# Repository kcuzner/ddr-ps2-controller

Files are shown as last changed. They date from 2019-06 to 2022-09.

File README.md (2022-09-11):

# Dance-Dance-Revolution PS2 Controller

Kevin Cuzner

## Introduction

This is my attempt at a low-cost, but high quality DIY DDR controller which is compatible with the Sony PlayStation 2.

The firmware is based loosely on my [Pop-N-Music PS2 Controller](https://github.com/kcuzner/pop-n-music-controller).
though I've rewritten it to be closer to my current style.

Although it would be cool to use an STM32 or other advanced ARM controller, that is overkill for what this is. Turns
out, a $0.60 AVR microcontroller can meet all the digital requirements without even needing a 3.3V regulator. To that
end, here is the main featureset:

 - ATTiny20 microcontroller (QFN package, 12 I/O). There are two personalities:
   - The PSX bus interface. This takes input from up to 6 buttons and operates the upstream PSX bus to the PlayStation
     2.
   - The switch controller. This takes input from up to 4 foot switches and produces a single output which is cabled to
     the PSX bux interface board.
 - Single PCB which fits both personalities.
 - Edge-facing LEDs for pad illumination.
   - Strangely enough, it was cheaper to just use a constant-current controlled LED driver than to use a discrete MOSFET
     of an appropriate size.

## Project Status

 - This project has not been fully assembled or tested. But:
 - Firmware builds and installs on both board personalities.
 - The LED/Switch boards work great! Mostly. Some quirks with the LEDs always being partially on,
   but whatever.
 - With a [USB-PS2 adapter](https://www.amazon.com/gp/product/B01J4JVFXI) I've verified on an
   oscilloscope that the controller board can be polled and that it appears to send back the
   correct responses. So the PSX bus implementation is at least superficially correct.
 - The switch boards can connect to the controller board and on an oscilloscope I've verified that
   everything toggles.

Some things still remain I can think of off the top of my head:

 - I need to test it with an actual PS2. Now to convince my wife to let me touch her PS2...
 - I need to verify that the button/switch mappings are correct for a dance pad. I unfortunately
   didn't mark the PCB silkscreen in any way for that, so I'm going to have to resort to colored
   tape, paint, or something else to keep the myriad cables straight while wiring this up.
 - I need to actually construct the wood/metal/plastic enclosure for this. I have a plan, but it's
   not posted here.

## References

 - http://www.raphnet.net/electronique/psx_adaptor/Playstation.txt
 - https://gist.github.com/scanlime/5042071
 - https://store.curiousinventor.com/guides/PS2/
 - https://blog.nearfuturelaboratory.com/2008/06/19/playstation2-logic-analysis/

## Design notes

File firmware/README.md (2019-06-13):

# DDR PS2 Controller Firmware

This firmware is for the ATTiny20 and uses avr-gcc. It creates two personalities which are separate and distinct
functions of the single PCB:

 - The Controller: This is the PSX Bus controller which handles input from 6 switches and communicates over the PSX bus.
 - The Switch: Each foot switch has 4 separate physical switches. This collates the 4 switches into a single control
   line and also operates some LEDs.

## Build Prerequisites

 - make
 - avr-gcc
 - avr-binutils
 - avrdude

## How to build

This uses a recursive makefile system to build the two personality components. To begin the build process, the `make`
command is invoked from this directory. It will pass along the target to the component makefiles. Here are some example
invocations:

```
$ make
```

This invocation will build the default target for both components.

```
$ make all switch
```

This invocation will build the `all` target for the switch component.

```
$ make clean
```

This invocation will build the `clean` target for both components.

```
$ make install controller
```

This invocation will build the `install` target for the controller component

To describe the format for the commands more generally, invoking `make` in this folder has the following syntax:

```
make [TARGET] [[COMPONENT] [[COMPONENT]..]]
```

Where each `[TARGET]` is something that can be built in the subdirectory and each `[COMPONENT]` is a subdirectory in
this folder which has been designated in the `Makefile` as a component subdirectory.

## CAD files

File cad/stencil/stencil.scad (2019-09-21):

// Solder Stencil, tuned for the MP Select Mini 3D Printer
// Material: ABS
// Nozzle: 0.2mm
// Layer height: <0.1mm

// We use various dimensions, depending on where I pulled them from (PCB CAD is inches, physical measurements are mm)
inches = 25.4;
mm = 1;
degrees = 1;

//Set up for higher resolution circles
$fn = 60;

//Variables
//Generally:
//  Width is the X direction
//  Length is the Y direction

pad_manifold = 0.01 * mm; //padding for maintaining a manifold (avoiding zero-width shapes)

/////// PCB Dimensions

pcb_width = 100 * mm;
pcb_length = 40 * mm;
pcb_thickness = 1.6 * mm;

/////// Solder Paste Properties

// The solder paste should be exported with the entire page as its area, but
// without board edges. The board's corner is at a nice even number.
paste_origin_x = 100 * mm;
paste_origin_y = 90 * mm;

/////// Stencil

stencil_width = pcb_width + 10 * mm;
stencil_length = pcb_length + 10 * mm;
stencil_thickness = 0.1 * mm;

/////////////// Solder Stencil //////////////////

module PasteLayer() {
  translate([-paste_origin_x - pcb_width/2, -paste_origin_y - pcb_length/2, 0])
    linear_extrude(height=pcb_thickness + stencil_thickness + pad_manifold)
      import("../ddr-ps2-controller-F_Paste.svg");
}

module PcbStandin() {
  translate([-pcb_width/2, -pcb_length/2, -pad_manifold])
    cube([pcb_width, pcb_length, pcb_thickness + pad_manifold]);
}

module SolderStencil() { //`make` me
  rotate([180*degrees, 0, 0])
    difference() {
      translate([-stencil_width/2, -stencil_length/2, 0])
        cube([stencil_width, stencil_length, stencil_thickness + pcb_thickness]);
      PasteLayer();
      PcbStandin();
    }
}

SolderStencil();

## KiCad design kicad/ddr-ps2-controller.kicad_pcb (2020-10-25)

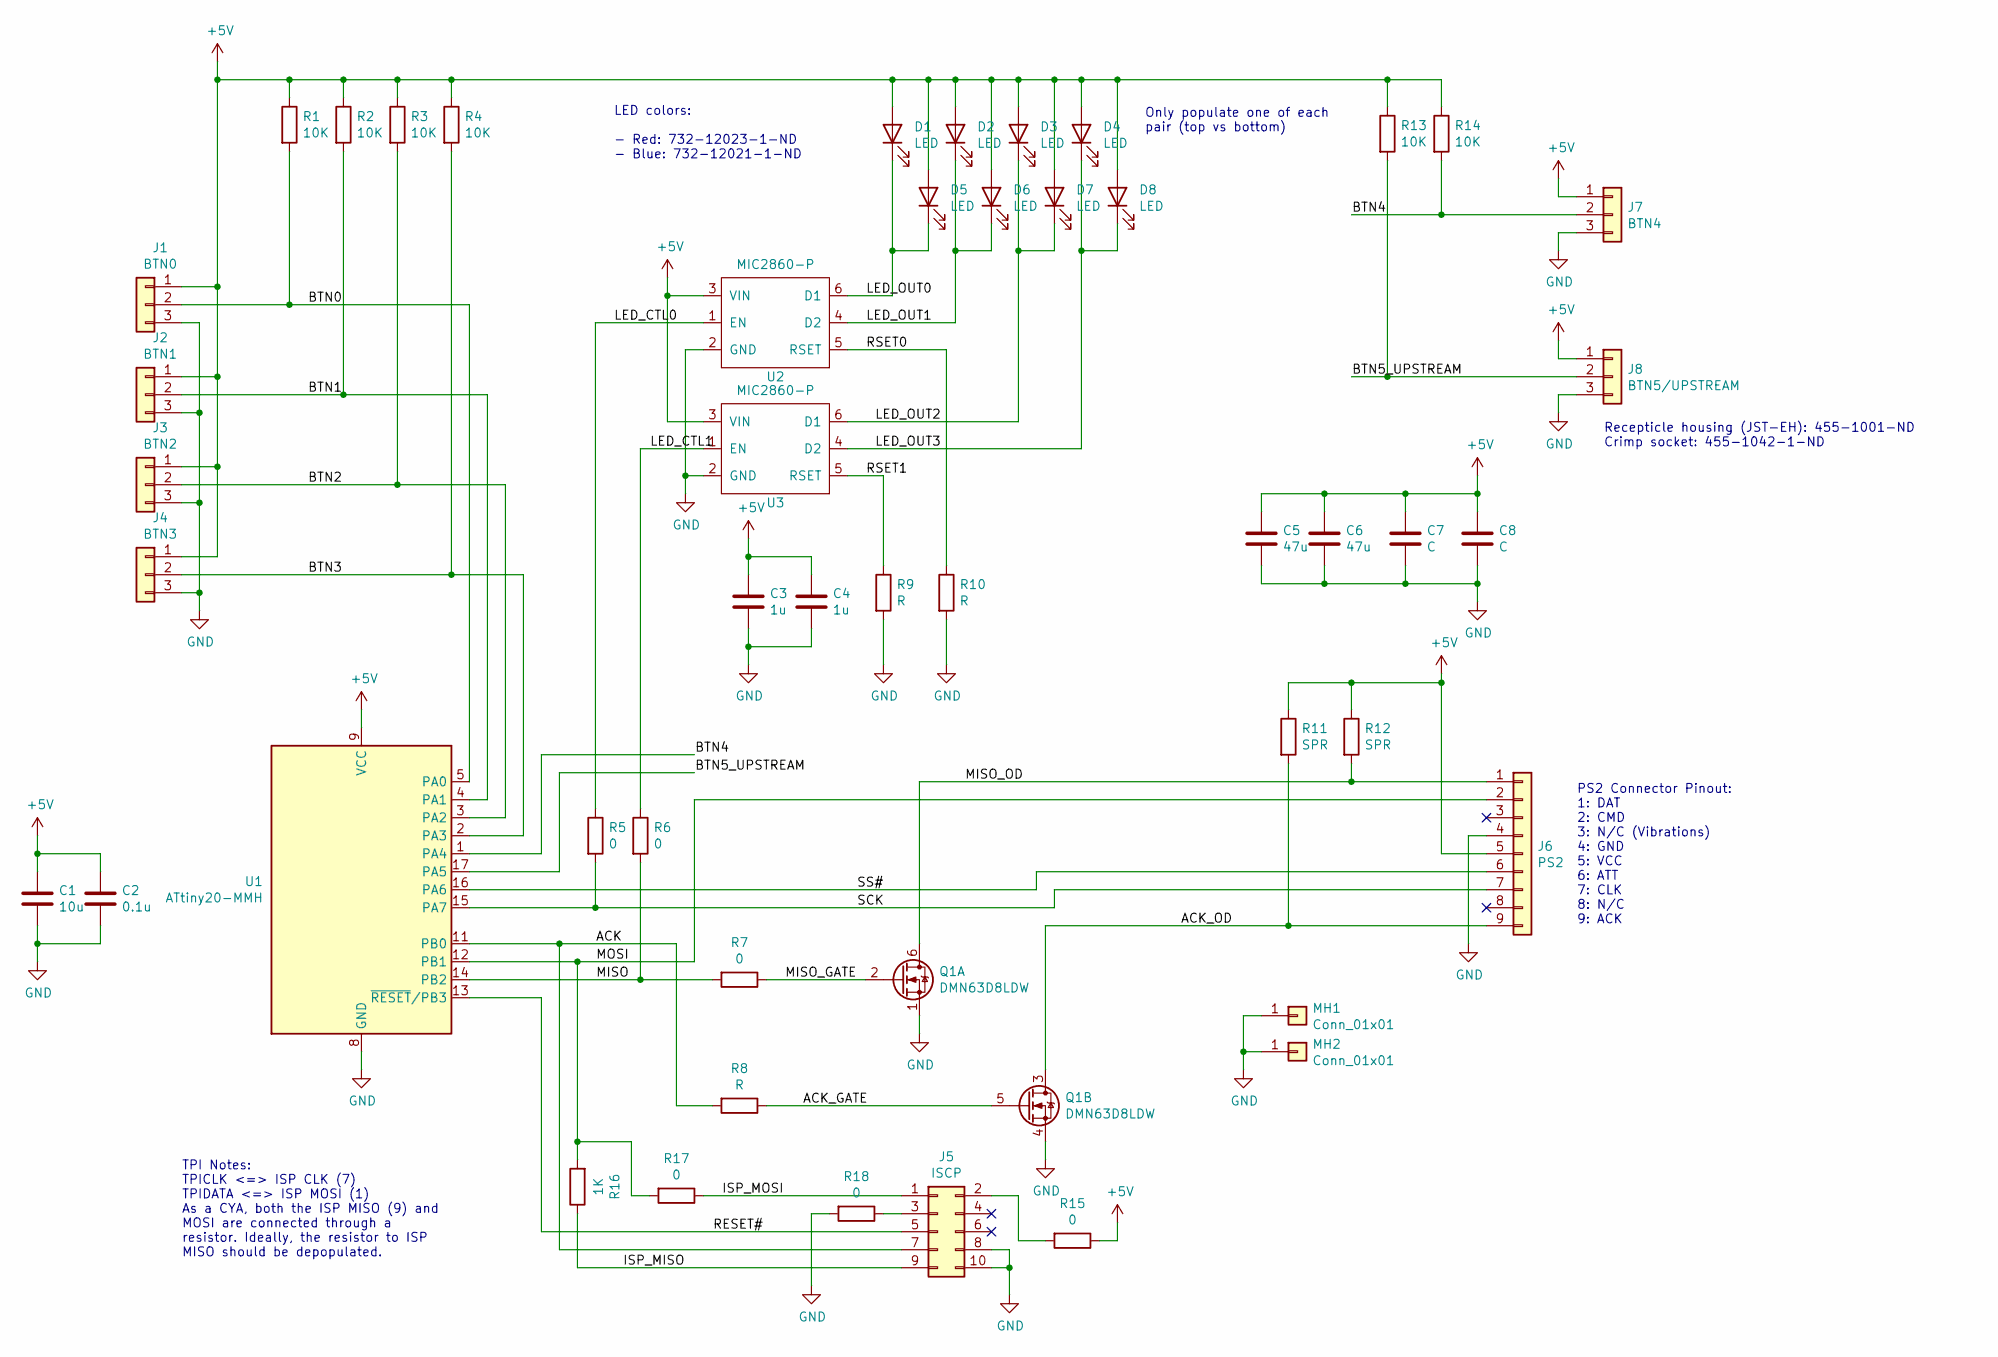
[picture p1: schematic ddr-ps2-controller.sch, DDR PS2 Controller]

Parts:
C1: 10u; C_0603_1608Metric
C2: 0.1u; R_0402_1005Metric
C3, C4: 1u; R_0402_1005Metric
C5, C6: 47u; C_1210_3225Metric; Part Number 587-1780-1-ND
C7, C8: C; C_0805_2012Metric
D1, D2, D3, D4, D5, D6, D7, D8: LED; Wurth_WL-SMSW_LED; Part Number 732-12021-1-ND
J1: BTN0; JST_EH_3_RA; Part Number 455-1626-ND
J2: BTN1; JST_EH_3_RA; Part Number 455-1626-ND
J3: BTN2; JST_EH_3_RA; Part Number 455-1626-ND
J4: BTN3; JST_EH_3_RA; Part Number 455-1626-ND
J5: ISCP; CnC_3020_10_0300
J6: PS2; PinHeader_1x09_P2.54mm_Vertical
J7: BTN4; JST_EH_3_RA; Part Number 455-1626-ND
J8: BTN5/UPSTREAM; JST_EH_3_RA; Part Number 455-1626-ND
MH1, MH2: Conn_01x01; MountingHole_4.3mm_M4_Pad_Via
Q1: DMN63D8LDW; SOT-363_SC-70-6; Part Number DMN63D8LDW-7CT-ND
R1, R2, R3, R4, R13, R14: 10K; R_0402_1005Metric
R5, R6, R7, R17: 0; R_0402_1005Metric
R8, R9, R10: R; R_0402_1005Metric
R11, R12: SPR; R_0402_1005Metric
R15, R18: 0; R_0603_1608Metric
R16: 1K; R_0402_1005Metric
U1: ATtiny20-MMH; QFN-20-1EP_3x3mm_P0.45mm_EP1.6x1.6mm; Part Number ATTINY20-MMH-ND
U2, U3: MIC2860-P; SOT-363_SC-70-6; Part Number 576-3897-1-ND

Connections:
+5V: C1.1, C2.1, C3.1, C4.1, C5.1, C6.1, C7.1, C8.1, D1.2 (A), D2.2 (A), D3.2 (A), D4.2 (A), D5.2 (A), D6.2 (A), D7.2 (A), D8.2 (A), J1.1, J2.1, J3.1, J4.1, J6.5, J7.1, J8.1, R1.1, R2.1, R3.1, R4.1, R11.1, R12.1, R13.1, R14.1, R15.1, U1.9 (VCC), U2.3 (VIN), U3.3 (VIN)
/ACK: J5.7, R8.2, U1.11 (PB0)
/ACK_GATE: Q1.5 (G), R8.1
/ACK_OD: J6.9, Q1.3 (D), R11.2
/BTN0: J1.2, R1.2, U1.5 (PA0)
/BTN1: J2.2, R2.2, U1.4 (PA1)
/BTN2: J3.2, R3.2, U1.3 (PA2)
/BTN3: J4.2, R4.2, U1.2 (PA3)
/BTN4: J7.2, R14.2, U1.1 (PA4)
/BTN5_UPSTREAM: J8.2, R13.2, U1.17 (PA5)
/ISP_MISO: J5.9, R16.1
/ISP_MOSI: J5.1, R17.1
/LED_CTL0: R5.1, U2.1 (EN)
/LED_CTL1: R6.1, U3.1 (EN)
/LED_OUT0: D1.1 (K), D5.1 (K), U2.6 (D1)
/LED_OUT1: D2.1 (K), D6.1 (K), U2.4 (D2)
/LED_OUT2: D3.1 (K), D7.1 (K), U3.6 (D1)
/LED_OUT3: D4.1 (K), D8.1 (K), U3.4 (D2)
/MISO: R6.2, R7.2, U1.14 (PB2)
/MISO_GATE: Q1.2 (G), R7.1
/MISO_OD: J6.1, Q1.6 (D), R12.2
/MOSI: J6.2, R16.2, R17.2, U1.12 (PB1)
/RESET#: J5.5, U1.13 (~RESET~/PB3)
/RSET0: R10.1, U2.5 (RSET)
/RSET1: R9.1, U3.5 (RSET)
/SCK: J6.7, R5.2, U1.15 (PA7)
/SS#: J6.6, U1.16 (PA6)
GND: C1.2, C2.2, C3.2, C4.2, C5.2, C6.2, C7.2, C8.2, J1.3, J2.3, J3.3, J4.3, J5.8, J5.10, J6.4, J7.3, J8.3, MH1.1, MH2.1, Q1.1 (S), Q1.4 (S), R9.2, R10.2, R18.2, U1.8 (GND), U1.21 (GND), U2.2 (GND), U3.2 (GND)
unnamed: J5.2, R15.2
unnamed: J5.3, R18.1

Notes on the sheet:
LED colors: - Red: 732-12023-1-ND - Blue: 732-12021-1-ND
PS2 Connector Pinout: 1: DAT 2: CMD 3: N/C (Vibrations) 4: GND 5: VCC 6: ATT 7: CLK 8: N/C 9: ACK
Recepticle housing (JST-EH): 455-1001-ND‎ Crimp socket: 455-1042-1-ND‎
Only populate one of each pair (top vs bottom)
TPI Notes: TPICLK <=> ISP CLK (7) TPIDATA <=> ISP MOSI (1) As a CYA, both the ISP MISO (9) and MOSI are connected through a resistor. Ideally, the resistor to ISP MISO should be depopulated.

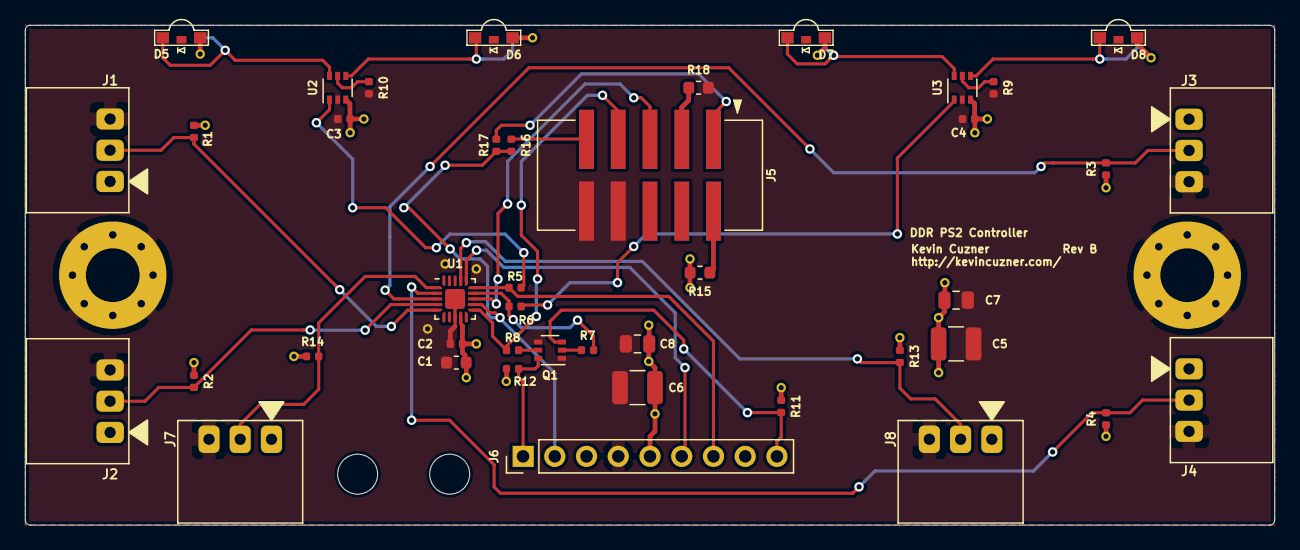
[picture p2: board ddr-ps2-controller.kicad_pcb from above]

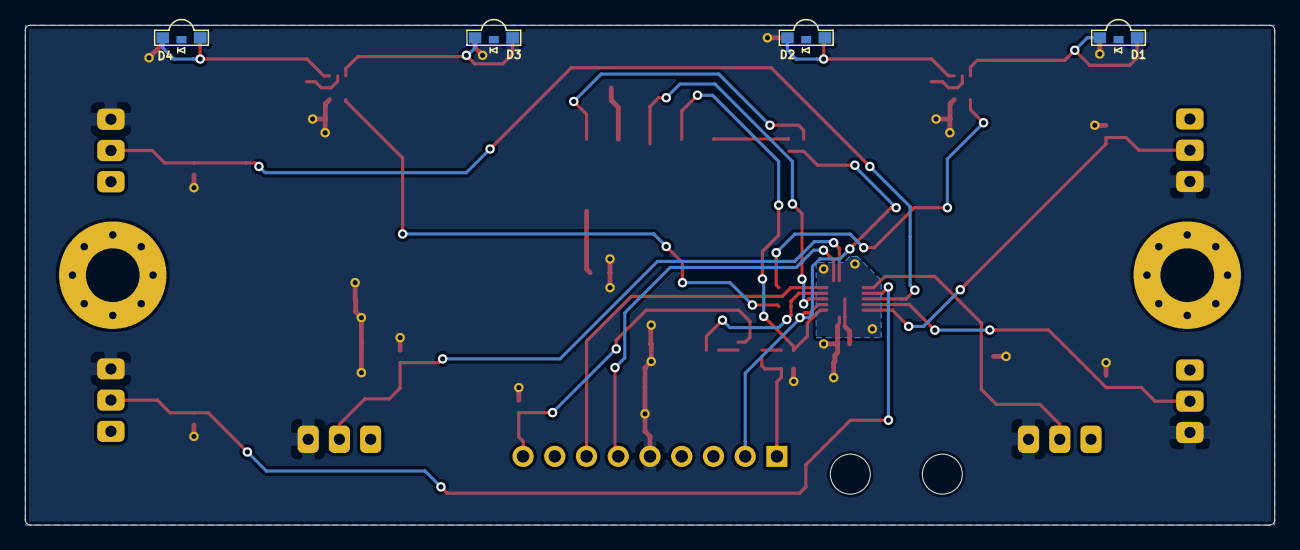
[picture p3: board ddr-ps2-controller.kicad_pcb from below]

Board: 2 copper layers, 100.0 x 40.0 mm, 48 parts (4 on the bottom side), 30 nets.

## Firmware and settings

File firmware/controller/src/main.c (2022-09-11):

/**
 * DDR PS2 Controller
 *
 * Controller Component
 *
 * Kevin Cuzner
 */

#include "switches.h"
#include "psx_pad.h"
#include "psx.h"

#include <stdint.h>
#include <avr/interrupt.h>
#include <avr/io.h>

int main(void)
{
  // Speed up the clock
  CCP = 0xD8;
  CLKPSR = 0;

  // Configure all pins. They are default input and this personality uses them
  // all as inputs.
  switches_init();
  // Configure the PSX Bus
  psx_init();

  sei();

  while (1)
  {
    PSXPadButtons buttons = PSX_PAD_NONE;
    if (switches_get_state(PINS_BTN0))
      buttons |= PSX_PAD_UP;
    if (switches_get_state(PINS_BTN1))
      buttons |= PSX_PAD_RIGHT;
    if (switches_get_state(PINS_BTN2))
      buttons |= PSX_PAD_DOWN;
    if (switches_get_state(PINS_BTN3))
      buttons |= PSX_PAD_LEFT;
    if (switches_get_state(PINS_BTN4))
      buttons |= PSX_PAD_O;
    if (switches_get_state(PINS_BTN5))
      buttons |= PSX_PAD_X;
    psx_pad_update(buttons);
  }

  return 0;
}

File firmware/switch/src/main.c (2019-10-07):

/**
 * DDR PS2 Controller
 *
 * Switch Component
 *
 * Kevin Cuzner
 */

#include "switches.h"
#include "leds.h"

#include <avr/interrupt.h>

int main(void)
{
  uint8_t asserted = 0;

  // Configure all pins.
  switches_init();

  // Configure LEDs
  leds_init();

  sei();

  while (1)
  {
    asserted = 0;
    for (uint8_t i = PINS_BTN0; i < PINS_BTN5; i++)
    {
      if (switches_get_state(i))
        asserted = 1;
    }
    if (asserted)
      leds_set();
    switches_set_state(PINS_BTN5, asserted);
  }

  return 0;
}

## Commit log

2019-06-13 Initial PCB layout with CAD files for new footprints
    [ddr-ps2-controller.kicad_pcb, ddr-ps2-controller.sch]
2019-06-16 Added "fuse" support
    Strictly speaking, it is not fuses. It is a particular region of
    configuration memory. But it is called a fuse in the datasheet and it is
    a shame that it isn't supported by the AVR stdlib.
2019-08-08 Changed connector to the far cheaper JST-EH
    [ddr-ps2-controller.kicad_pcb, ddr-ps2-controller.sch]
2019-08-08 Added rounding to the board edges
    [ddr-ps2-controller.kicad_pcb]
2019-08-08 Minor cleanup with LED alignment
    [ddr-ps2-controller.kicad_pcb]
2019-08-08 Fixing board outline shape issue
    [ddr-ps2-controller.kicad_pcb]
2019-08-17 Rev A Gerber out
    [ddr-ps2-controller-B_Cu.gbr, ddr-ps2-controller-B_Mask.gbr, ddr-ps2-controller-B_SilkS.gbr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]
2019-08-19 Added initial pad implementation
    This is not very efficient, as it reads the port each time it asks for
    the pin state. I may end up going back to how I did it with the
    popnmusic controller, although that wasn't very fancy.
2019-08-20 Added LED system for the switch component
2019-09-21 Removed a random unprintable charcter from some part numbers
    [ddr-ps2-controller.sch]
2019-09-21 First pass at the solder stencil
    [stencil.scad]
2019-09-21 Reduced stencil size to fit on printer
    [stencil.scad]
2019-09-21 Added datasheet for micrel LED driver
2019-10-07 Many small changes to get the switch firmware working
    It now works, though I suspect my first board is defective on at least
    one switch (just need to run the iron over the pins again on one side
    that's a little light).
2020-10-25 Updating PCB and Schematic for rev B, fixing TPI and footprint issues
    The programming interface for this microcontroller is TPI and for some
    reason I wired it to be ISP. This implements a greenwire I did to work
    around it.
    I did not double-check the footprint for the SMD header. I've now added
    the footprint from the datasheet.
    Schematic library updated
    [ddr-ps2-controller-B_Cu.gbr, ddr-ps2-controller-B_Mask.gbr, ddr-ps2-controller-B_SilkS.gbr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]
2022-09-11 Fixing MISO bad-actor behavior after SS# deassert
    [main.c, psx.c]
2022-09-11 Fixing button press polarity
    [psx.c]
